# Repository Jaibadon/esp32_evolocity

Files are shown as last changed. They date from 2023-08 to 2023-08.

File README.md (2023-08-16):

# Evolocity Monotoring board using ESP32-C3 Chip with external flash capabilitiy
RPM, Voltage, Current and temperature sensing

AH1390 Hall Effect(Rpm)
ACS711 Current monitor

SPX3819 Low dropout reg

Designed in Kicad 7.0

Low pass Pi matching nework simulated using 4Nec2.

Quality factor = 2

Pi Matching results:

Xp1 = ~2pF

Xp2= ~2pF

Xs = 2.2nH

Due to Xp values being in the <~3pF range they are negligible and will be part of the parasitic capacitance.

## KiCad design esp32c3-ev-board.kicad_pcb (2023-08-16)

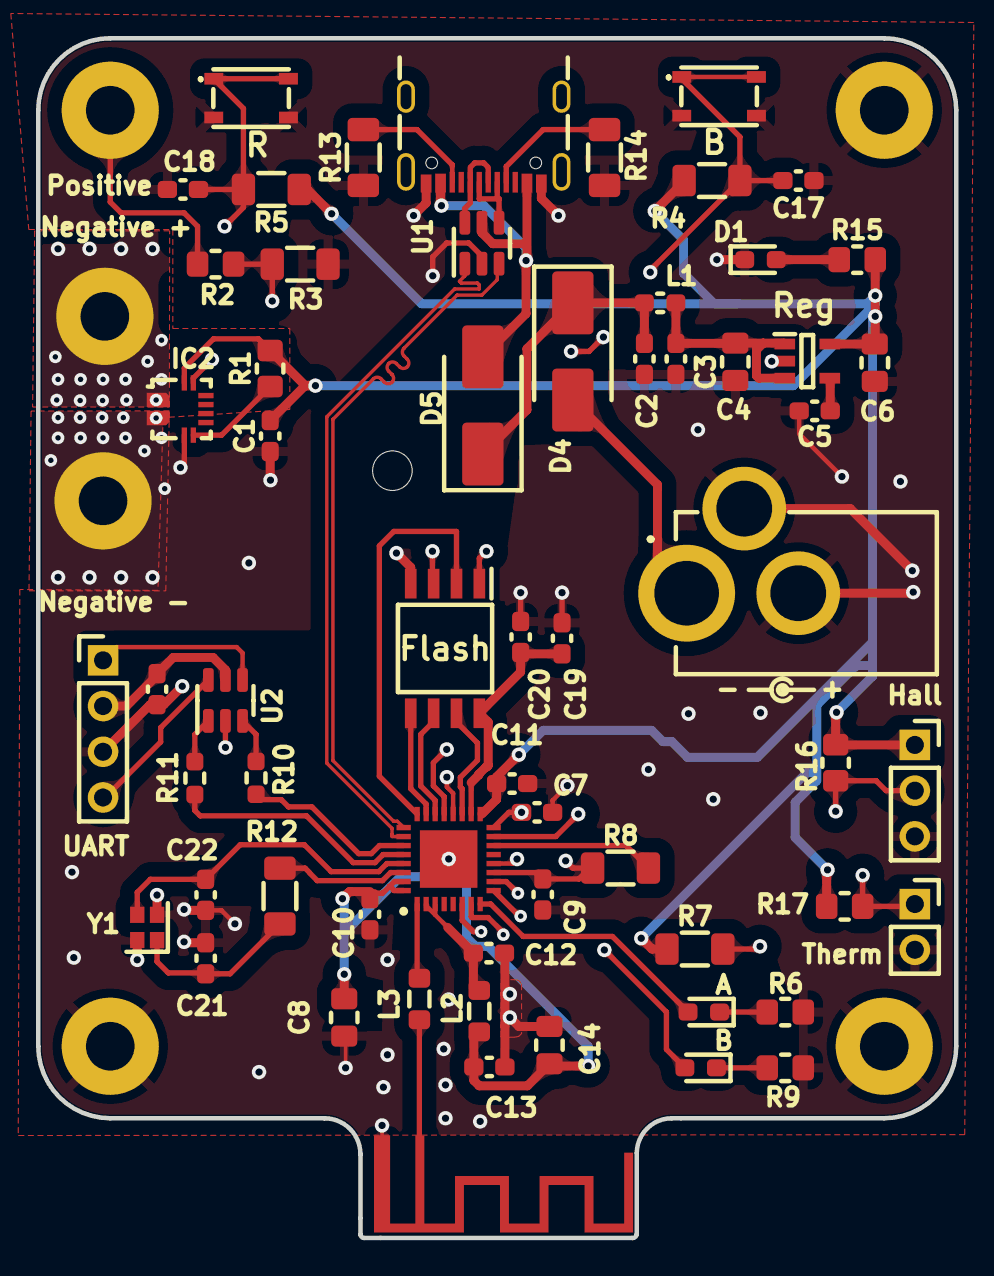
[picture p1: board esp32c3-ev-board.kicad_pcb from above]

Board: 4 copper layers, 51.0 x 66.7 mm, 68 parts (0 on the bottom side), 48 nets.

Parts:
A: LED A; LED_0603_1608Metric_Pad1.05x0.95mm_HandSolder
ANT1: antenna
B: LED B; LED_0603_1608Metric_Pad1.05x0.95mm_HandSolder
B#2: SW_DPST_x2; SKRPADE010
C1: 0.1 uF; C_0603_1608Metric_Pad1.08x0.95mm_HandSolder
C2, C3, C5, C9, C10, C11, C12, C13, C17, C18, C19, C23: 100n; C_0603_1608Metric_Pad1.08x0.95mm_HandSolder
C4, C6, C8, C14: 10u; C_0805_2012Metric_Pad1.18x1.45mm_HandSolder
C7: 100nF; C_0603_1608Metric_Pad1.08x0.95mm_HandSolder
C20: 10u; C_0603_1608Metric_Pad1.08x0.95mm_HandSolder
C21, C22: 10p; C_0603_1608Metric_Pad1.08x0.95mm_HandSolder
D1: LED A; LED_0603_1608Metric_Pad1.05x0.95mm_HandSolder
D4, D5: D; D_SMB_Handsoldering
Flash: W25Q128JVSIQ; SOIC127P790X216-8N
H1, H3, H4: MountingHole_Pad; MountingHole_2.7mm_M2.5_Pad
H7: MountingHole_Pad; MountingHole_2.2mm_M2
Hall: Screw_Terminal_01x03; PinSocket_1x03_P2.54mm_Vertical
IC2: ACS711EEXTK-31AB-T; Allegro_QFN-12-10-1EP_3x3mm_P0.5mm
IC3: ESP32-C3FH4; QFN50P500X500X90-33N-D
J2: DC Connecter; KLDX0202A
J5: USB_C_Receptacle_USB2.0; USB_C_Receptacle_GCT_USB4105-xx-A_16P_TopMnt_Horizontal
L1: 2n2; L_0603_1608Metric_Pad1.05x0.95mm_HandSolder
L2, L3: 2n2; L_0805_2012Metric_Pad1.05x1.20mm_HandSolder
Negative +: MountingHole_Pad; MountingHole_2.7mm_M2.5_Pad
Negative -: MountingHole_Pad; MountingHole_2.7mm_M2.5_Pad
Positive: MountingHole_Pad; MountingHole_2.7mm_M2.5_Pad
R: SW_DPST_x2; SKRPADE010
R1: 1kR; R_0805_2012Metric_Pad1.20x1.40mm_HandSolder
R2: 100k; R_0805_2012Metric_Pad1.20x1.40mm_HandSolder
R3: 5.1k; R_1206_3216Metric_Pad1.30x1.75mm_HandSolder
R4, R5, R7, R8, R13, R14: 5k1; R_1206_3216Metric_Pad1.30x1.75mm_HandSolder
R6, R9, R15, R16, R17: 1k; R_0805_2012Metric_Pad1.20x1.40mm_HandSolder
R10, R11: 470R; R_0603_1608Metric_Pad0.98x0.95mm_HandSolder
R12: 22R; R_1206_3216Metric_Pad1.30x1.75mm_HandSolder
Reg: SPX3819M5-L-3-3; SOT95P280X145-5N
Therm: Battery Neg(Series); PinSocket_1x02_P2.54mm_Vertical
U1, U2: USBLC6-2SC6; SOT-23-6
UART: Conn_01x04_Pin; PinHeader_1x04_P2.54mm_Vertical
Y1: 40MHZ; Crystal_SMD_2016-4Pin_2.0x1.6mm

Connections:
3V3 RF: C12.1, IC3.2 (VDD3P3_1), IC3.3 (VDD3P3_2), L2.1
5vUSB: D5.2 (A), J5.A4 (VBUS), J5.A9 (VBUS), J5.B4 (VBUS), J5.B9 (VBUS), U1.5 (VBUS)
+3.3V: C1.2, C6.1, C8.1, C9.1, C10.1, C11.1, C13.1, C14.1, Hall.1, IC2.12 (VCC), IC3.11 (VDD3P3_RTC), IC3.17 (VDD3P3_CPU), IC3.31 (VDDA_1), IC3.32 (VDDA_2), L2.2, R1.2, R4.1, R5.1, R7.1, R8.1, R15.2, R16.1, R17.2, Reg.5 (VOUT)
CHIPEN: C18.1, IC3.7 (CHIP_EN), R.1 (A), R.2 (B), R5.2
CurMeas: B#2.1 (A), B#2.2 (B), C17.1, IC2.11 (VIOUT), IC3.15 (GPIO9), R4.2
LED A: A.2 (A), IC3.8 (GPIO3)
LED B: B.2 (A), IC3.12 (MTCK)
unnamed: ANT1.1, L3.1
unnamed: C21.1, R12.2, Y1.1
unnamed: D1.2 (A), R15.1
unnamed: A.1 (K), R6.2
unnamed: D4.2 (A), J2.1
unnamed: B.1 (K), R9.2
unnamed: C5.1, Reg.4 (ADJ/BYP)
unnamed: C3.1, C4.1, L1.2, Reg.1 (VIN), Reg.3 (EN)
unnamed: IC2.6 (~FAULT), R1.1
unnamed: IC3.6 (GPIO2), R7.2
unnamed: IC3.14 (GPIO8), R8.2
unnamed: IC3.1 (LNA_IN), L3.2
unnamed: Hall.2, IC3.10 (MTDI), R16.2
unnamed: IC3.9 (MTMS), R17.1, Therm.1
unnamed: Flash.6 (CLK), IC3.22 (SPICLK)
unnamed: Flash.1 (/CS), IC3.21 (SPICS0)
unnamed: Flash.5 (DI_(IO0)), IC3.23 (SPID)
unnamed: Flash.7 (HD(IO3)), IC3.19 (SPIHD)
unnamed: Flash.2 (DO_(IO1)), IC3.24 (SPIQ)
unnamed: Flash.3 (/WP_(IO2)), IC3.20 (SPIWP)
unnamed: IC3.27 (U0RXD), R10.2
unnamed: IC3.28 (U0TXD), R11.2
unnamed: C19.1, C20.1, Flash.8 (VCC), IC3.18 (VDD_SPI)
unnamed: C22.1, IC3.29 (XTAL_N), Y1.3
unnamed: IC3.30 (XTAL_P), R12.1
unnamed: U2.4 (I/O2), UART.1
unnamed: U2.6 (I/O1), UART.4
unnamed: J5.A5 (CC1), R14.1
unnamed: J5.B5 (CC2), R13.2
unnamed: J5.A6 (D+), J5.B6 (D+), U1.6 (I/O1)
unnamed: J5.A7 (D-), J5.B7 (D-), U1.4 (I/O2)
Reg Neg: ANT1.2, B#2.3 (B), B#2.4 (B), C1.1, C2.2, C3.2, C4.2, C5.2, C6.2, C7.2, C8.2, C9.2, C10.2, C11.2, C12.2, C13.2, C14.2, C17.2, C18.2, C19.2, C20.2, C21.2, C22.2, C23.2, D1.1 (K), Flash.4 (GND), H1.1, H3.1, H4.1, Hall.3, IC2.4 (IP-), IC2.5 (GND), IC3.33 (GND), J2.2, J2.3, J5.A1 (GND), J5.A12, J5.B1, J5.B12, Negative -.1, R.3 (B), R.4 (B), R3.2, R6.1, R9.1, R13.1, R14.2, Reg.2 (GND), Therm.2, U1.2 (GND), U2.2 (GND), UART.3, Y1.2, Y1.4
Reg Pos: C2.1, D4.1 (K), D5.1 (K), L1.1
UARTRX: R10.1, U2.3 (I/O2)
UARTTX: R11.1, U2.1 (I/O1)
USBD+: IC3.26 (GPIO19), U1.1 (I/O1)
USBD-: IC3.25 (GPIO18), U1.3 (I/O2)
UnregNeg(furthest from bat term): IC2.1 (IP+), Negative +.1
UnregPos: Positive.1, R2.1
VBUS: C23.1, U2.5 (VBUS), UART.2
VoltMeas: C7.1, IC3.16 (GPIO10), R2.2, R3.1

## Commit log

2023-07-25 Init commit
    [esp32c3-ev-board.kicad_pcb, esp32c3-ev-board.kicad_sch]
2023-07-25 Crystal added
    [esp32c3-ev-board.kicad_pcb, esp32c3-ev-board.kicad_sch]
2023-07-25 rando resistor test
    [esp32c3-ev-board.kicad_sch]
2023-07-26 Flash Memory Added
    [EDI2CAP.CFG, SOIC127P790X216-8N.PcbLib, W25Q128JVSIQ.SchLib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]
2023-07-26 Cleaning up Schematic
    [esp32c3-ev-board.kicad_sch]
2023-07-26 Added Chip Enable Switch
    [esp32c3-ev-board.kicad_sch]
2023-07-26 Tidy values and usb/esd prot
    [esp32c3-ev-board.kicad_sch]
2023-07-27 working on voltage and voltage mux
    [esp32c3-ev-board.kicad_sch]
2023-07-27 Added Power supply diodes
    [esp32c3-ev-board.kicad_sch]
2023-07-27 box test
    [esp32c3-ev-board.kicad_sch]
2023-07-27 added LEDs
    [esp32c3-ev-board.kicad_sch]
2023-07-28 rearranging schematic
    [esp32c3-ev-board.kicad_sch]
2023-08-01 change voltreg
    [esp32c3-ev-board.kicad_sch]
2023-08-01 volt reg work
    [esp32c3-ev-board.kicad_sch]
2023-08-02 Added Footprints and transfered to PCB
    [esp32c3-ev-board.kicad_pcb, esp32c3-ev-board.kicad_sch]
2023-08-02 Arranged some of the components for less crosses in the pcb
    [esp32c3-ev-board.kicad_pcb]
2023-08-04 Did some pcb changes
    [esp32c3-ev-board.kicad_pcb]
2023-08-09 Changed footprints
    [esp32c3-ev-board.kicad_pcb, esp32c3-ev-board.kicad_sch]
2023-08-09 Assigned new switch and DC connecter footprints
    [esp32c3-ev-board.kicad_pcb, esp32c3-ev-board.kicad_sch]
2023-08-09 placement and routing ideas
    [esp32c3-ev-board.kicad_pcb, esp32c3-ev-board.kicad_sch]
2023-08-09 shape and placement nearly finished, doing perephirals next
    [esp32c3-ev-board.kicad_pcb, esp32c3-ev-board.kicad_sch]
2023-08-10 almost completed board layout
    [esp32c3-ev-board.kicad_pcb, esp32c3-ev-board.kicad_sch]
2023-08-10 starting outline REMEMBER TO ORDER 100k resistor size 0805
    [esp32c3-ev-board.kicad_pcb, esp32c3-ev-board.kicad_sch]
2023-08-11 finished outline
    [esp32c3-ev-board.kicad_pcb, esp32c3-ev-board.kicad_sch]
2023-08-13 Almost finished
    [esp32c3-ev-board.kicad_pcb, esp32c3-ev-board.kicad_sch]
2023-08-15 finishing touches
    [esp32c3-ev-board.kicad_pcb]
2023-08-15 PCBWAY VER || SWITCHING TO JLC
    [esp32c3-ev-board-B_Cu.gbr, esp32c3-ev-board-B_Mask.gbr, esp32c3-ev-board-B_Paste.gbr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]
2023-08-15 ordered board
    [esp32c3-ev-board-B_Cu.gbr, esp32c3-ev-board-B_Mask.gbr, esp32c3-ev-board-B_Paste.gbr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]
2023-08-16 3d models
    [esp32c3-ev-board.kicad_pcb]
